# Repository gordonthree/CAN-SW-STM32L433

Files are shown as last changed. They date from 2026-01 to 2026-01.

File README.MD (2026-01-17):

# DC Power Distribution Module Controller
Compact controller board intended to interface with as many as four smart switch modules. Analog inputs for current and voltage sensing allow the controller to interrupt a load in place of a mechanical fuse or circuit breaker. An isolated CAN-FD interface provides expansion capability with other boards, displays and sensors.

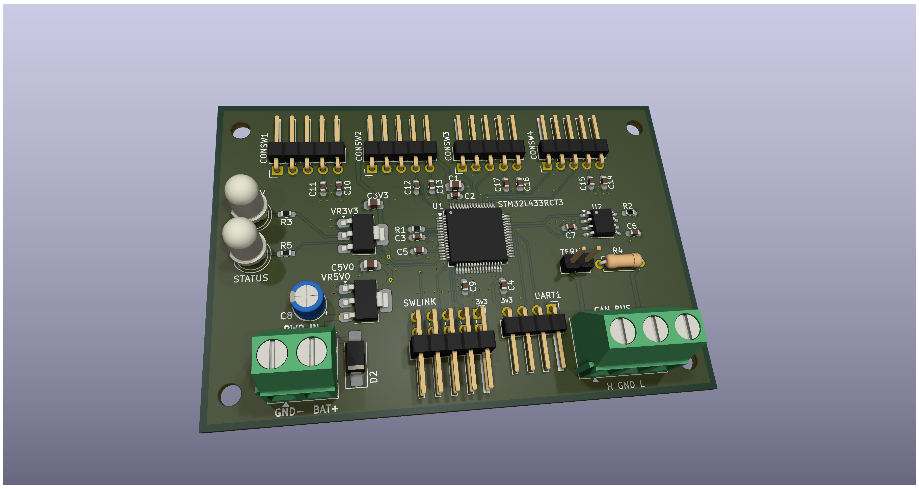
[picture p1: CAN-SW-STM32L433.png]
3d rendering of circuit board


# Control Node
* STM32L433 Microcontroller
* 3-pin terminal block for CANBUS connection with drain
* Pin-header connections for Profet Smart Switch modules
* Analog inputs for voltage and current sensing
* Jumper selected CAN terminator resistor
* LED indicator for 3.3v power
* LED indicator for status, controlled by the micro
* Bidirectional transient voltage protection diode for harsh environments
* Debugging header for UART1 serial port as well as SWLINK programming

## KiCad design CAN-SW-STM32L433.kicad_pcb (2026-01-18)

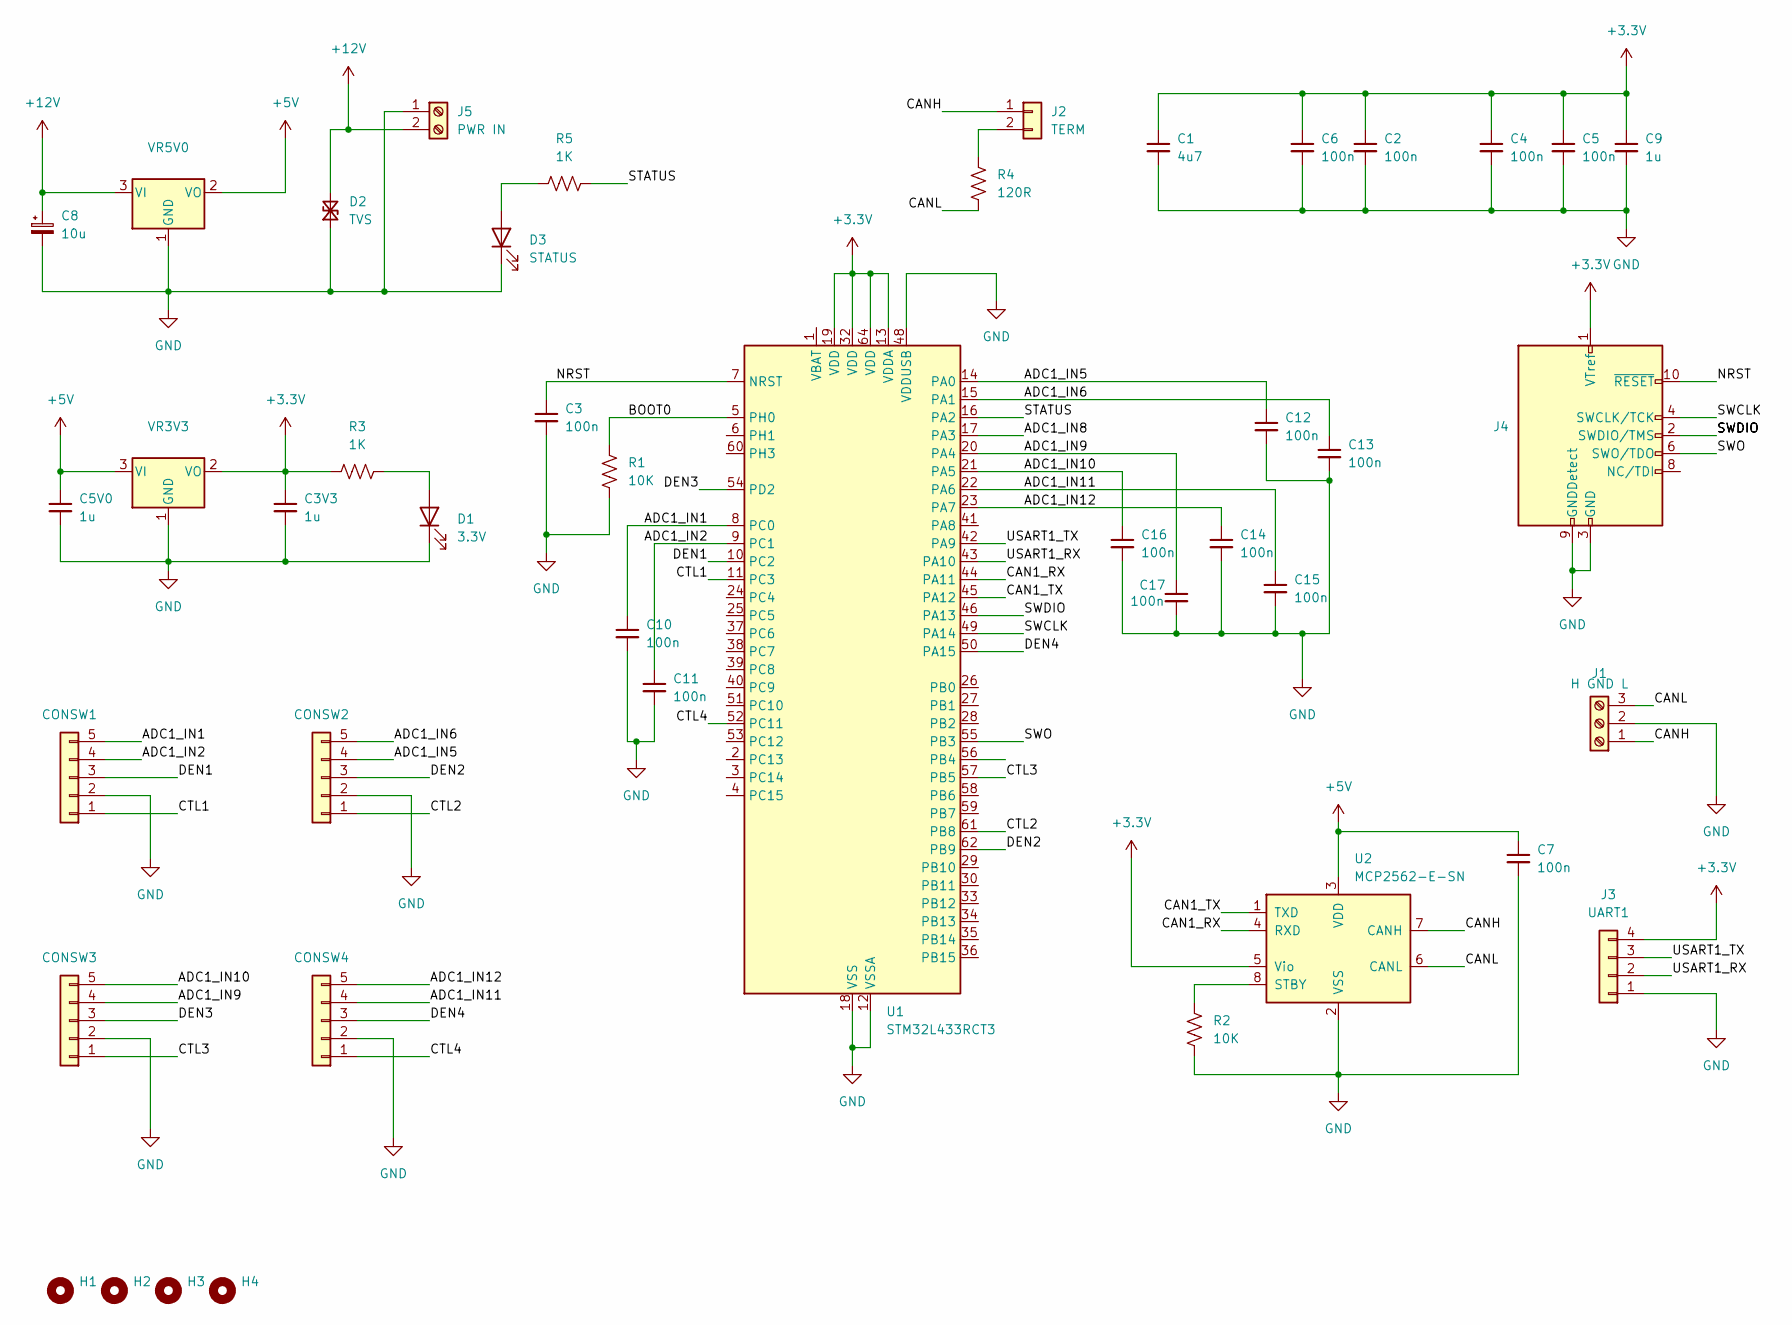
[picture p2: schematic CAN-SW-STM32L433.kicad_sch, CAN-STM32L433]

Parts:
C1: 4u7; C_0805_2012Metric_Pad1.18x1.45mm_HandSolder
C2, C3, C4, C5, C6, C7, C10, C11, C12, C13, C14, C15, C16, C17: 100n; C_0603_1608Metric_Pad1.08x0.95mm_HandSolder
C3V3, C5V0: 1u; C_0805_2012Metric_Pad1.18x1.45mm_HandSolder
C8: 10u; CP_Radial_D5.0mm_P2.50mm
C9: 1u; C_0603_1608Metric_Pad1.08x0.95mm_HandSolder
CONSW1, CONSW2, CONSW3, CONSW4: Conn_01x05; PinHeader_1x05_P2.54mm_Horizontal
D1: 3.3V; LED_D5.0mm_Clear
D2: TVS; D_SMA_Handsoldering
D3: STATUS; LED_D5.0mm_Clear
H1, H2, H3, H4: MountingHole; MountingHole_3.2mm_M3_DIN965
J1: H GND L; TerminalBlock_Phoenix_MKDS-1,5-3_1x03_P5.00mm_Horizontal
J2: TERM; PinHeader_1x02_P2.54mm_Vertical
J3: UART1; PinHeader_1x04_P2.54mm_Horizontal
J4: SWLINK; PinHeader_2x05_P2.54mm_Horizontal
J5: PWR IN; TerminalBlock_Phoenix_MKDS-1,5-2_1x02_P5.00mm_Horizontal
R1, R2: 10K; R_0603_1608Metric_Pad0.98x0.95mm_HandSolder
R3, R5: 1K; R_0603_1608Metric_Pad0.98x0.95mm_HandSolder
R4: 120R; R_Axial_DIN0207_L6.3mm_D2.5mm_P7.62mm_Horizontal
U1: STM32L433RCT3; LQFP-64_10x10mm_P0.5mm
U2: MCP2562-E-SN; SOIC-8_3.9x4.9mm_P1.27mm
VR3V3: TLV1117-33; SOT-223-3_TabPin2
VR5V0: TLV1117-50; SOT-223-3_TabPin2

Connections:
+3.3V: C1.1, C2.1, C3V3.1, C4.1, C5.1, C6.1, C9.1, J3.4, J4.1 (VTref), R3.1, U1.13 (VDDA), U1.19 (VDD), U1.32 (VDD), U1.64 (VDD), U2.5 (Vio), VR3V3.2 (VO)
+5V: C5V0.1, C7.1, U2.3 (VDD), VR3V3.3 (VI), VR5V0.2 (VO)
+12V: C8.1, D2.2 (A2), J5.2, VR5V0.3 (VI)
/ADC1_IN1: C10.1, CONSW1.5, U1.8 (PC0)
/ADC1_IN2: C11.1, CONSW1.4, U1.9 (PC1)
/ADC1_IN5: C12.1, CONSW2.4, U1.14 (PA0)
/ADC1_IN6: C13.1, CONSW2.5, U1.15 (PA1)
/ADC1_IN8: U1.17 (PA3)
/ADC1_IN9: C17.1, CONSW3.4, U1.20 (PA4)
/ADC1_IN10: C16.1, CONSW3.5, U1.21 (PA5)
/ADC1_IN11: C15.1, CONSW4.4, U1.22 (PA6)
/ADC1_IN12: C14.1, CONSW4.5, U1.23 (PA7)
/BOOT0: R1.1, U1.5 (PH0)
/CAN1_RX: U1.44 (PA11), U2.4 (RXD)
/CAN1_TX: U1.45 (PA12), U2.1 (TXD)
/CANH: J1.1, J2.1, U2.7 (CANH)
/CANL: J1.3, R4.2, U2.6 (CANL)
/CTL1: CONSW1.1, U1.11 (PC3)
/CTL2: CONSW2.1, U1.61 (PB8)
/CTL3: CONSW3.1, U1.57 (PB5)
/CTL4: CONSW4.1, U1.52 (PC11)
/DEN1: CONSW1.3, U1.10 (PC2)
/DEN2: CONSW2.3, U1.62 (PB9)
/DEN3: CONSW3.3, U1.54 (PD2)
/DEN4: CONSW4.3, U1.50 (PA15)
/NRST: C3.1, J4.10 (~RESET), U1.7 (NRST)
/STATUS: R5.2, U1.16 (PA2)
/SWCLK: J4.4 (SWCLK/TCK), U1.49 (PA14)
/SWDIO: J4.2 (SWDIO/TMS), U1.46 (PA13)
/SWO: J4.6 (SWO/TDO), U1.55 (PB3)
/USART1_RX: J3.2, U1.43 (PA10)
/USART1_TX: J3.3, U1.42 (PA9)
GND: C1.2, C2.2, C3.2, C3V3.2, C4.2, C5.2, C5V0.2, C6.2, C7.2, C8.2, C9.2, C10.2, C11.2, C12.2, C13.2, C14.2, C15.2, C16.2, C17.2, CONSW1.2, CONSW2.2, CONSW3.2, CONSW4.2, D1.1 (K), D2.1 (A1), D3.1 (K), J1.2, J3.1, J4.3 (GND), J4.5 (GND), J4.9 (GNDDetect), J5.1, R1.2, R2.2, U1.12 (VSSA), U1.18 (VSS), U1.31 (VSS), U1.47 (VSS), U1.48 (VDDUSB), U1.63 (VSS), U2.2 (VSS), VR3V3.1 (GND), VR5V0.1 (GND)
unnamed: D1.2 (A), R3.2
unnamed: D3.2 (A), R5.1
unnamed: J2.2, R4.1
unnamed: R2.1, U2.8 (STBY)

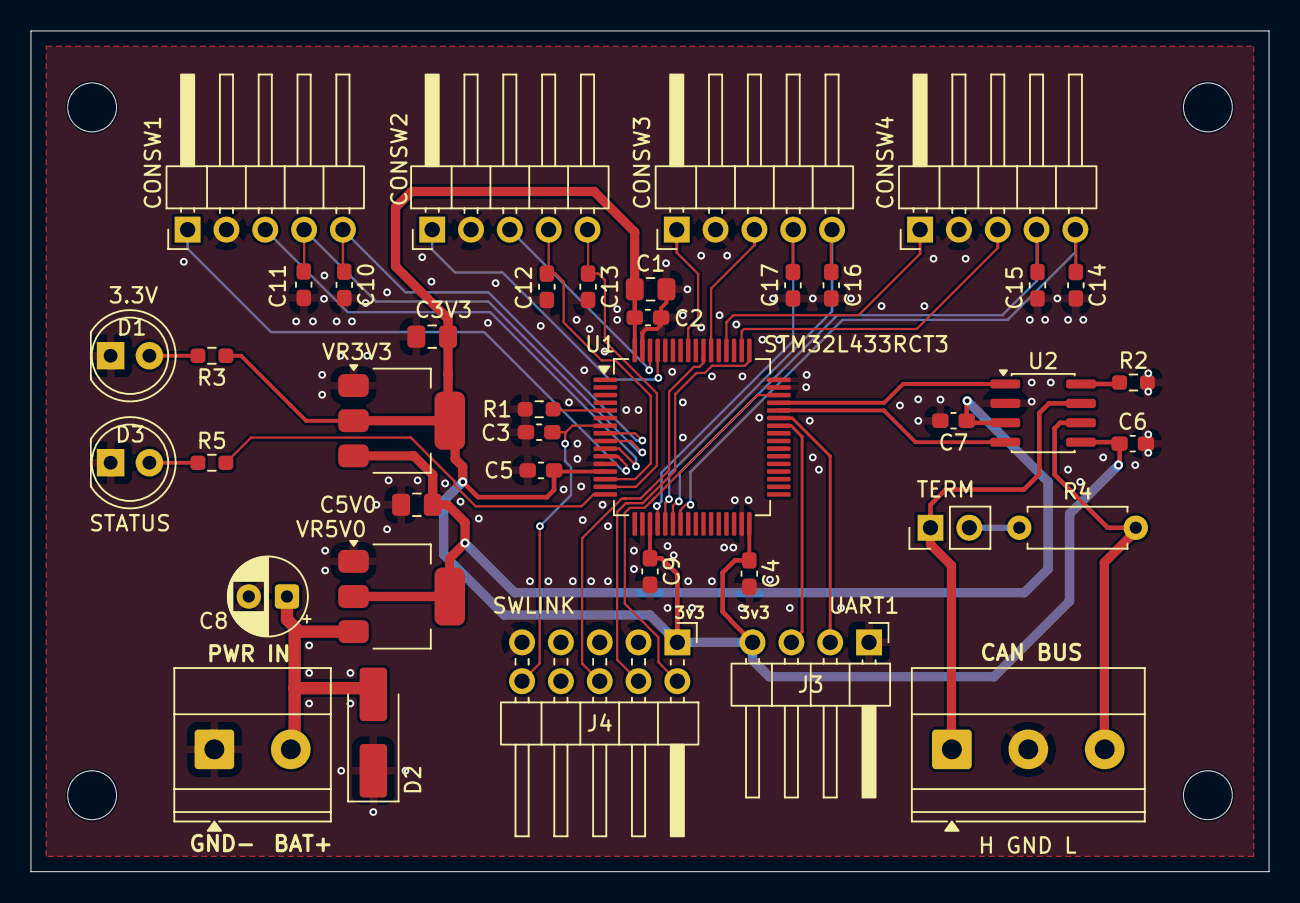
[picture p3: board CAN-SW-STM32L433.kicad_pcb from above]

Board: 2 copper layers, 81.0 x 55.0 mm, 44 parts (0 on the bottom side), 36 nets.

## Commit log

2026-01-12 dive in with kicad
    [CAN-SW-STM32L433.kicad_pcb, CAN-SW-STM32L433.kicad_sch]
2026-01-13 still adding parts, working on basic layout
    [CAN-SW-STM32L433.kicad_pcb, CAN-SW-STM32L433.kicad_sch]
2026-01-14 almost done adding parts, working more on layout
    [CAN-SW-STM32L433.kicad_pcb, CAN-SW-STM32L433.kicad_sch]
2026-01-14 more progress on the layout, fixed connector sizes for uart and swlink
    [CAN-SW-STM32L433.kicad_pcb, CAN-SW-STM32L433.kicad_sch]
2026-01-14 routing getting tricky with just two layers
    [CAN-SW-STM32L433.kicad_pcb, CAN-SW-STM32L433.kicad_sch]
2026-01-15 layout mostly complete, working on DRC
    [CAN-SW-STM32L433.kicad_pcb, CAN-SW-STM32L433.kicad_sch]
2026-01-15 layout and drc complete, fix some silkscreen issues
    [CAN-SW-STM32L433.kicad_pcb, CAN-SW-STM32L433.kicad_sch]
2026-01-15 add gerber export folder to ignore list
2026-01-15 moved power and can connectors, fixed some trace routing
    [CAN-SW-STM32L433.kicad_pcb, CAN-SW-STM32L433.kicad_sch]
2026-01-15 silkscreen tweaks
    [CAN-SW-STM32L433.kicad_pcb, CAN-SW-STM32L433.kicad_sch]
2026-01-17 added status led and tvs diode
    [CAN-SW-STM32L433.kicad_pcb, CAN-SW-STM32L433.kicad_sch]
2026-01-17 fix TVS package size, do some layout tweaks
    [CAN-SW-STM32L433.kicad_pcb, CAN-SW-STM32L433.kicad_sch]
2026-01-17 add 3d board rendering
2026-01-17 update readme with more info and board rendering
2026-01-18 layout tweak
    [CAN-SW-STM32L433.kicad_pcb]

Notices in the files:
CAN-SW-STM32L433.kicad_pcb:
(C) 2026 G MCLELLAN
